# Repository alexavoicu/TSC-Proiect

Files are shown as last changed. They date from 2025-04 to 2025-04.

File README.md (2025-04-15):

Proiect OpenBook - Voicu Alexa-Andreea 331 CD

1. Diagrama bloc cu componentele



2. BOM cu componentele 3D folosite

| Qty | Component | Mouser Link | Datasheet Link |
|-----|---|---|---|
| 26  | C0402C560J4HACAUTO | [link](https://ro.mouser.com/ProductDetail/KEMET/C0402C560J4HACAUTO?qs=j%252B1pi9TdxUae00jFMoJVSQ%3D%3D) | [link](https://ro.mouser.com/datasheet/2/447/KEM_C1007_X8R_ULTRA_150C_SMD-3316375.pdf) |
| 6 | PGB1010603MR | [link](https://ro.mouser.com/ProductDetail/Littelfuse/PGB1010603MR?qs=gu7KAQ731URLg4GSnNNN7Q%3D%3D) | [link](https://www.littelfuse.com/assetdocs/pulseguard-esd-suppressors-pgb1-datasheet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) |
| 3 | MBR0530 | [link](https://ro.mouser.com/ProductDetail/onsemi/MBR0530T3G?qs=3JMERSakebpEmdUS6GetdQ%3D%3D) | [link](https://www.onsemi.com/PowerSolutions/product.do?id=MBR0530T3G) |
| 1 | USBLC6-2SC6Y | [link](https://ro.mouser.com/ProductDetail/STMicroelectronics/USBLC6-2SC6Y?qs=gNDSiZmRJS%2FOgDexvXkdow%3D%3D) | [link](https://ro.mouser.com/datasheet/2/389/usblc6_2sc6y-1852505.pdf) |
| 2 | SD0805S020S1R0 | [link](https://ro.mouser.com/ProductDetail/KYOCERA-AVX/SD0805S020S1R0?qs=jCA%252BPfw4LHbpkAoSnwrdjw%3D%3D) | [link](https://ro.mouser.com/datasheet/2/40/schottky-3165252.pdf) |
| 1 | BD5229G-TR | [link](https://ro.mouser.com/ProductDetail/ROHM-Semiconductor/BD5229G-TR?qs=4kLU8WoGk0vvnhrrYwdszw%3D%3D) | [link](https://fscdn.rohm.com/en/products/databook/datasheet/ic/power/voltage_detector/bd52xxg-e.pdf) |
| 1 | XC6220A331MR-G | [link](https://ro.mouser.com/ProductDetail/Torex-Semiconductor/XC6220A331MR-G?qs=AsjdqWjXhJ8ZSWznL1J0gg%3D%3D) | [link](https://ro.mouser.com/datasheet/2/760/xc6220-3371556.pdf) |
| 1 | FH34SRJ-24S-0.5SH_99_ | [link](https://ro.mouser.com/ProductDetail/Hirose-Connector/FH34SRJ-24S-0.5SH99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) | [link](https://ro.mouser.com/datasheet/2/185/FH34SRJ_24S_0_5SH_99__CL0580_1255_6_99_2DDrawing_0-1615044.pdf) |
| 1 | USB4110-GF-A | [link](https://ro.mouser.com/ProductDetail/GCT/USB4110-GF-A?qs=KUoIvG%2F9IlYiZvIXQjyJeA%3D%3D) | [link](https://ro.mouser.com/datasheet/2/837/GCT_USB4110_Product_Drawing___20k_cycles-3455479.pdf) |
| 1 | 112A-TAAR-R03_ATTEND | [link](https://www.digikey.ro/ro/products/detail/attend-technology/112A-TAAR-R03/17633923) | [link](https://www.attend.com.tw/data/download/file/112A-TAAR-R03_Spec.pdf) |
| 1 | TPC-4828 | [link](https://ro.mouser.com/ProductDetail/Wurth-Elektronik/744065151?qs=PGXP4M47uW53TYf%2FkIVaSQ%3D%3D) | [link](https://www.we-online.com/components/products/datasheet/744065151.pdf) |
| 1 | LG_R971-KN-1 | [link](https://ro.mouser.com/ProductDetail/ams-OSRAM/LG-R971-KN-1?qs=LsPilcdHE7EX1EB7GCLHxg%3D%3D) | [link](https://ro.mouser.com/datasheet/2/588/prd_pim_datasheet_2191277_EN_pdf-3419125.pdf) |
| 1 | MCP73831T-2ATI_OT | [link](https://ro.mouser.com/ProductDetail/Microchip-Technology/MCP73831T-2ATI-OT?qs=yUQqVecv4qsZbioEUu%252B83g%3D%3D) | [link](https://ro.mouser.com/datasheet/2/268/MCP73831_Family_Data_Sheet_DS20001984H-3441711.pdf) |
| 1 | PFMF.050.2 | [link](https://ro.mouser.com/ProductDetail/Schurter/PFMF.050.2?qs=1auRipcfynCums5v1iucSA%3D%3D) | [link](https://ro.mouser.com/datasheet/2/358/typ_PFMF-1275918.pdf) |
| 2 | Si1308EDL-T1-GE3 | [link](https://ro.mouser.com/ProductDetail/Vishay-Semiconductors/SI1308EDL-T1-GE3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) | [link](https://www.vishay.com/doc?63399) |
| 1 | DMG2305UX-7 | [link](https://ro.mouser.com/ProductDetail/Diodes-Incorporated/DMG2305UX-7?qs=L1DZKBg7t5F%2FNBHrjfxC%252Bg%3D%3D) | [link](https://www.diodes.com/assets/Datasheets/DMG2305UX.pdf) |
| 30  | RC0402FR-07100KL | [link](https://ro.mouser.com/ProductDetail/YAGEO/RC0402FR-07100KL?qs=mnq%2FyloZIXzTlUn7JAHSWg%3D%3D) | [link](https://ro.mouser.com/datasheet/2/447/YAGEO_PYu_RC_Group_51_RoHS_L_12-3313492.pdf) |
| 1 | BME688 | [link](https://ro.mouser.com/ProductDetail/Bosch-Sensortec/BME688?qs=IS%252B4QmGtzzqQoVDscqwx3A%3D%3D) | [link](https://ro.mouser.com/datasheet/2/783/bst_bme688_fl000-2307034.pdf) |
| 1 | CPH3225A | [link](https://ro.mouser.com/ProductDetail/Seiko-Semiconductors/CPH3225A?qs=3etwrb1wR%252BhUOph6lAO7eg%3D%3D) | [link](https://ro.mouser.com/datasheet/2/360/Seiko_Instruments_MicroBattery_E_20230330_2024Jan_-3561061.pdf) |
| 1 | W25Q512JVEIQ | [link](https://ro.mouser.com/ProductDetail/Winbond/W25Q512JVEIQ?qs=l7cgNqFNU1jw6svr3at6tA%3D%3D) | [link](https://ro.mouser.com/datasheet/2/949/Winbond_W25Q512JV_Datasheet-3240039.pdf) |
| 1 | ESP32-C6-WROOM-1-N8 | [link](https://ro.mouser.com/ProductDetail/Espressif-Systems/ESP32-C6-WROOM-1-N8?qs=8Wlm6%252BaMh8ST02Gmwp74cw%3D%3D) | [link](https://ro.mouser.com/datasheet/2/891/Espressif_ESP32_C6_WROOM_1__Datasheet_V0_1_PRELIMI-3239987.pdf) |
| 1 | DS3231SN# | [link](https://ro.mouser.com/ProductDetail/Analog-Devices-Maxim-Integrated/DS3231SN?qs=1eQvB6Dk1vhUlr8%2FOrV0Fw%3D%3D) | [link](https://ro.mouser.com/datasheet/2/609/DS3231-3421123.pdf) |
| 1 | MAX17048G+T10 | [link](https://ro.mouser.com/ProductDetail/Analog-Devices-Maxim-Integrated/MAX17048G%2bT10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) | [link](https://ro.mouser.com/datasheet/2/609/MAX17048_MAX17049-3469099.pdf) |
| 3 | EVQPU-JA-02K | [link](https://ro.mouser.com/ProductDetail/Panasonic/EVQ-PUJ02K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) | [link](https://4donline.ihs.com/images/VipMasterIC/IC/PANA/PANA-S-A0003211477/PANA-S-A0004028532-1.pdf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) |
| 1 | Ada 4328 | [link](https://ro.mouser.com/ProductDetail/Adafruit/4328?qs=wnTfsH77Xs6Ypm3wH0xoXg%3D%3D) | [link](https://www.snapeda.com/parts/4328/Adafruit/view-part/?ref=mouser) |
| 1 | T491B226K006AT | [link](https://ro.mouser.com/ProductDetail/KEMET/T491B226K006AT?qs=jcsBHvPDQt8yMdJgz62biA%3D%3D) | [link](https://ro.mouser.com/datasheet/2/447/KEM_T2005_T491-3316937.pdf) |

3. Descrierea în detaliu a funcționalității hardware

ESP32-C6 este microcontrollerul principal care coordonează funcționarea ebook readerului, ocupându-se de procesarea datelor și gestionarea comunicațiilor wireless. Acesta funcționează la 3.3V și dispune de interfețe versatile precum SPI, I2C și USB. Afișajul e-paper este controlat prin interfață SPI, oferind un transfer eficient al imaginilor, în timp ce aceeași magistrală SPI este partajată cu memoria externă NOR Flash, utilizată pentru stocarea firmware-ului și a resurselor grafice, și cu cardul microSD, destinat fișierelor ebook.

Prin interfața I2C sunt conectate mai multe module esențiale: ceasul de timp real DS3231SN, care păstrează ora exactă și poate semnala alarme; senzorul ambiental BME688, ce măsoară temperatura, umiditatea, presiunea și calitatea aerului; și monitorul de baterie MAX17048, care oferă informații despre tensiunea și nivelul de încărcare al bateriei. Această configurație I2C este extinsă prin conectorii Qwiic/Stemma QT, care permit adăugarea rapidă și modulară a altor senzori sau componente compatibile.

Dispozitivul este alimentat printr-un port USB-C care furnizează 5V, iar un regulator LDO convertește această tensiune la 3.3V pentru alimentarea componentelor interne. Încărcarea bateriei Li-Po este gestionată prin MCP73831, iar MAX17048 monitorizează constant nivelul bateriei. Un supercapacitor asigură alimentare de rezervă temporară, esențială pentru menținerea orei în cazul pierderii alimentării principale. Diodele TVS sunt incluse pentru protecție ESD pe liniile critice, asigurând durabilitatea dispozitivului.

E-paper-ul este optimizat energetic prin controlul alimentării cu MOSFET și prin monitorizarea semnalelor „busy” și „reset” cu ajutorul GPIO-urilor. Sistemul de stocare include atât memoria NOR Flash de 64MB, cât și cardul microSD, ambele gestionate eficient prin SPI. Interfața de utilizator este compusă din trei butoane: unul pentru resetare manuală, unul pentru intrarea în modul de boot și un buton configurabil pentru funcții speciale.

Pentru depanare și testare, placa include puncte de test (test pads) pentru semnale importante precum SPI, I2C, UART și diverse tensiuni. Acestea permit verificarea rapidă a funcționării sistemului în timpul dezvoltării sau mentenanței. Astfel, întreaga arhitectură este construită în jurul ESP32-C6, asigurând conectivitate flexibilă, eficiență energetică și extindere facilă a funcționalităților.

4. Pinii ESP32-C6

Pinii IO21 (SDA) și IO22 (SCL) sunt folosiți pentru comunicația I2C, partajați de RTC DS3231SN, senzorul BME688 și monitorul de baterie MAX17048. RTC-ul mai folosește IO0 (INT), IO1 (32KHz) și IO18 (RST). Cardul microSD folosește interfața SPI prin IO2 (MISO), IO4 (CS), IO6 (SCK) și IO7 (MOSI), iar memoria NOR Flash partajează SPI cu IO2, IO6, IO7 și adaugă IO11 pentru CS. E-paper-ul folosește IO6 și IO7 pentru date, cu IO3 (BUSY), IO5 (DC), IO10 (CS) și IO23 (RST) pentru control. Pentru butoane și funcții speciale se folosesc IO9 (BOOT), IO15 (CHANGE) și EN (RESET). Un pin rămâne neconectat (NC).

Imagini randări OpenBook

PCB 3D


Baterie


Display


OpenBook Asamblat


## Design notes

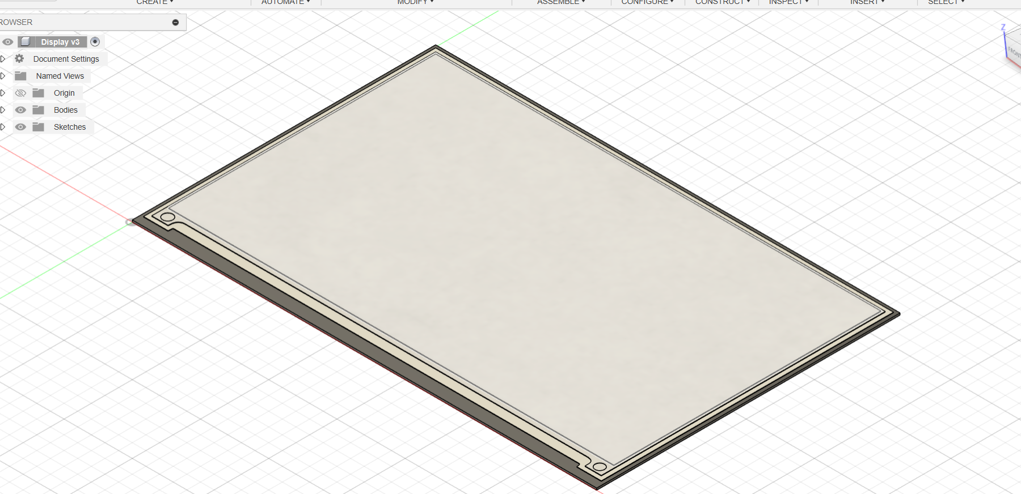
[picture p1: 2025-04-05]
Images/Display1.png

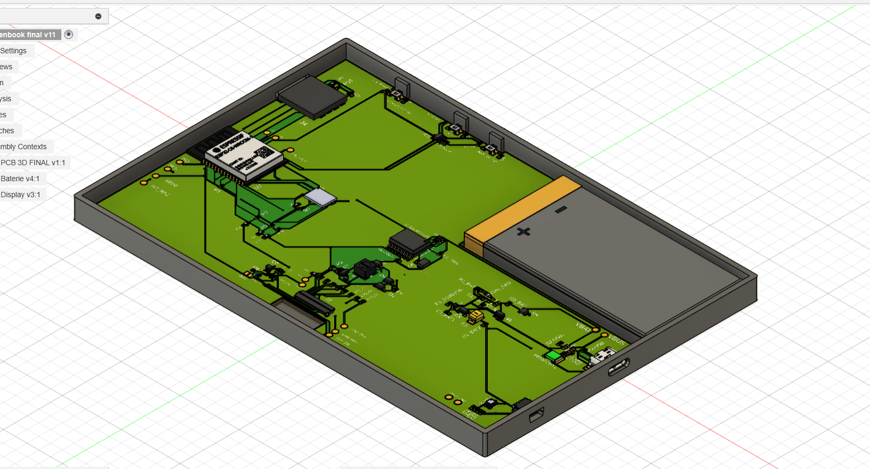
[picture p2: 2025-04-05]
Images/Openbook1.png

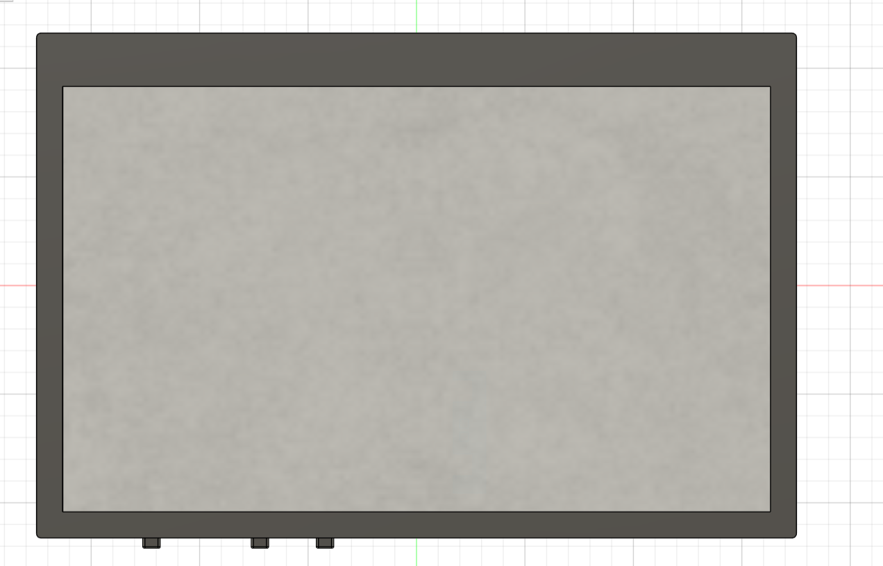
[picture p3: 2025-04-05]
Images/Openbook4.png

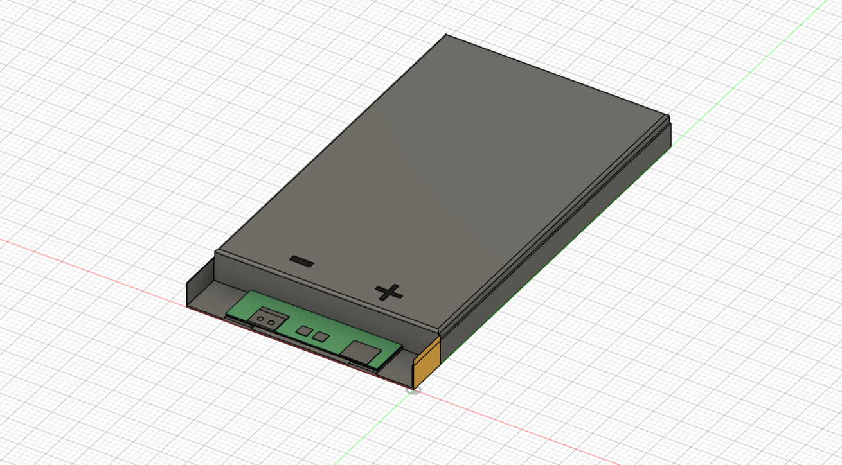
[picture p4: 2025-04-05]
Images/Baterie3.png

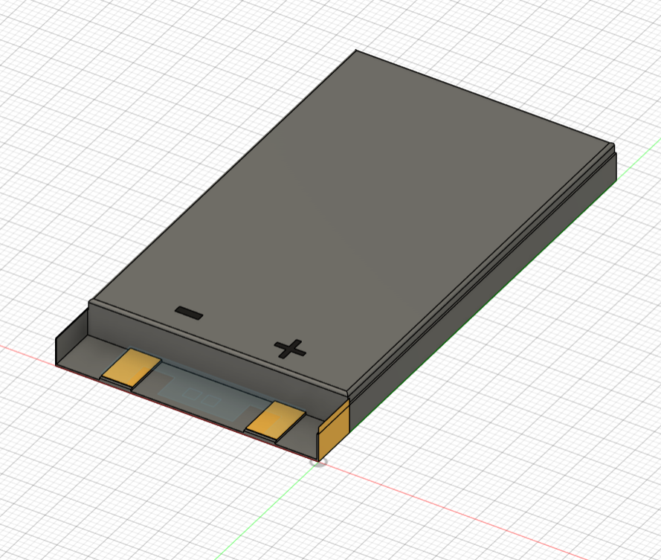
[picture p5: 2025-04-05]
Images/Baterie4.png

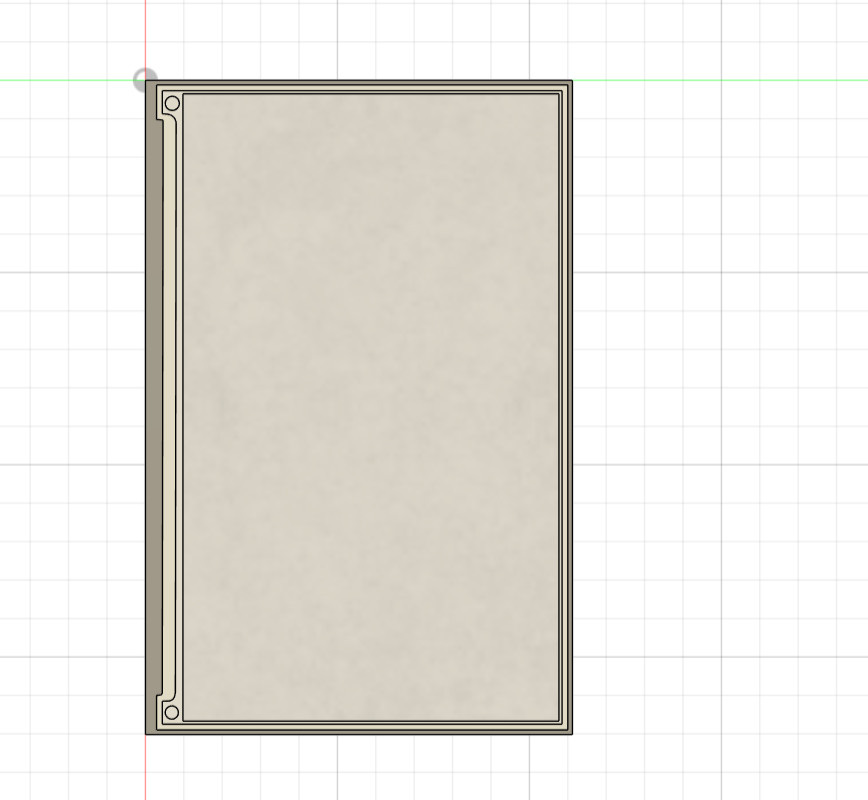
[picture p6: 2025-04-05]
Images/Display2.png

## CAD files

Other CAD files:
Mechanical/Openbook complet.f3z

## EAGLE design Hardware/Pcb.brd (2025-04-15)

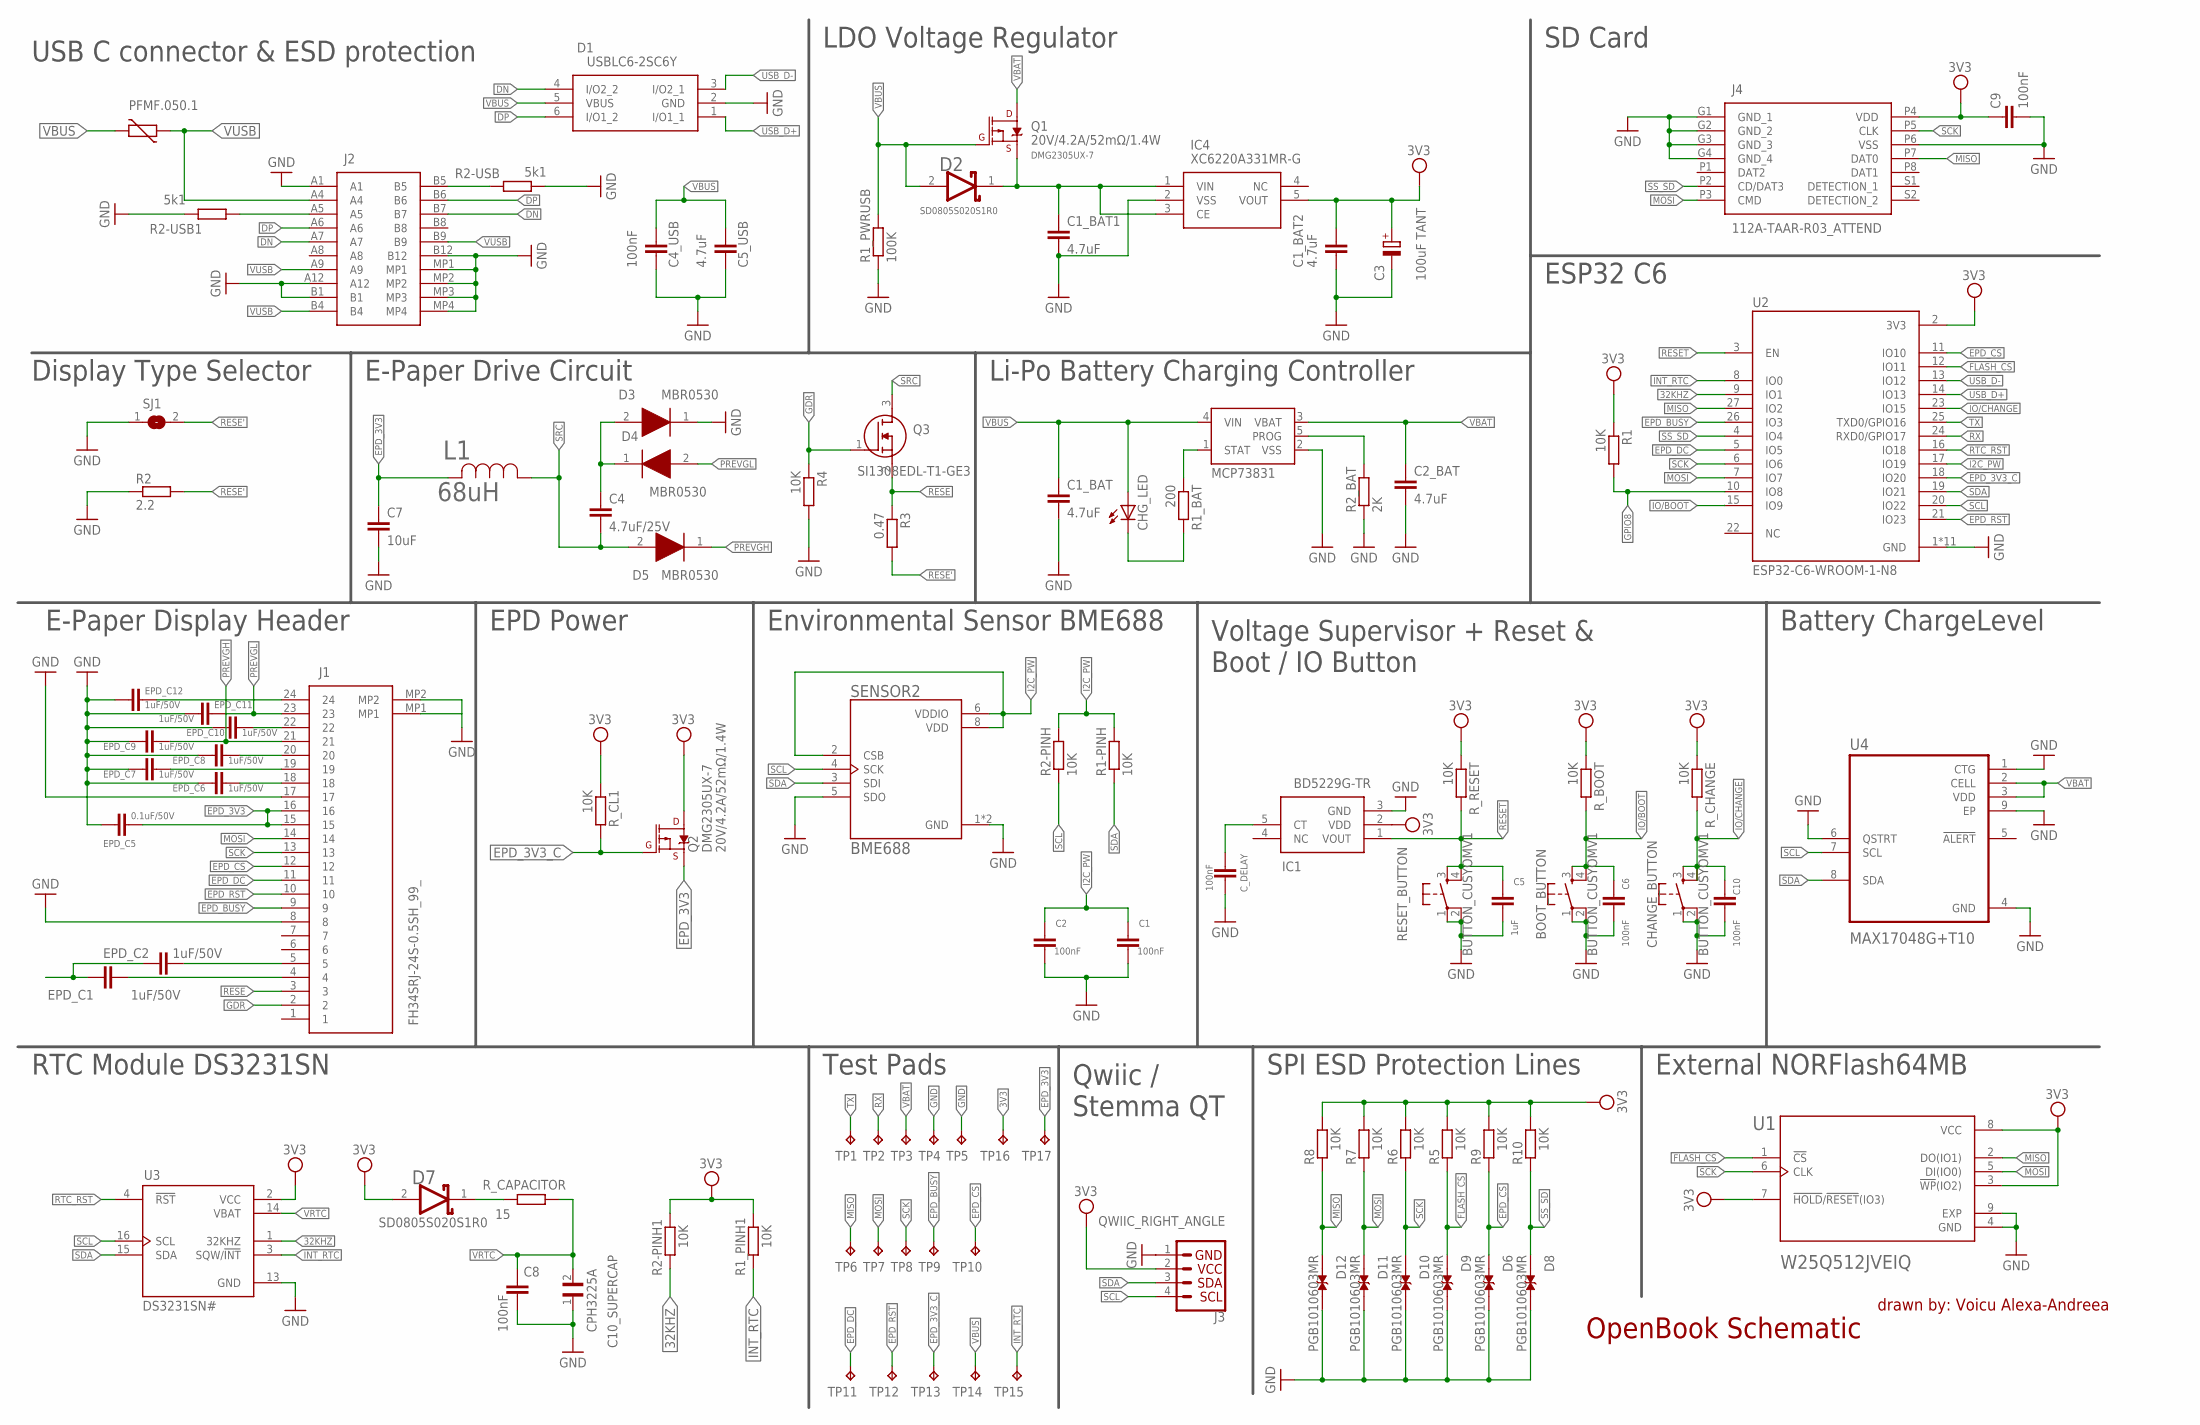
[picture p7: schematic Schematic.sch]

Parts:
BOOT_BUTTON: BUTTON_CUSYOMV1; MYBUTTON
C1, C2, C4_USB, C6, C8, C9, C10: 100nF; EAGLE-LTSPICE_C0402
C1_BAT, C1_BAT1, C1_BAT2, C2_BAT, C5_USB: 4.7uF; EAGLE-LTSPICE_C0402
C3: 100uF TANT; RCL_CT3528
C4: 4.7uF/25V; EAGLE-LTSPICE_C0402
C5: 1uF; EAGLE-LTSPICE_C0402
C7: 10uF; EAGLE-LTSPICE_C0402
C10_SUPERCAP: CPH3225A; CAPCP3225X100N
CHANGE_BUTTON: BUTTON_CUSYOMV1; MYBUTTON
CHG_LED: ADAFRUIT_LEDCHIP-LED0603; ADAFRUIT_CHIP-LED0603
C_DELAY: 100nF; EAGLE-LTSPICE_C0402
D1: USBLC6-2SC6Y; SOT95P280X145-6N
D2, D7: ESP32_WROVER_AVX---SD0805S020S1R0_AVX_SD0805S020S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; ESP32_WROVER_AVX---SD0805S020S1R0_AVX_SD0805S020S1R0_0
D3, D4, D5: MBR0530; SOD3716X135N
D6, D8, D9, D10, D11, D12: PGB1010603MR; DIOC1608X36N
EPD_C1, EPD_C2, EPD_C6, EPD_C7, EPD_C8, EPD_C9, EPD_C10, EPD_C11, EPD_C12: 1uF/50V; EAGLE-LTSPICE_C0402
EPD_C5: 0.1uF/50V; EAGLE-LTSPICE_C0402
IC1: BD5229G-TR; SOT95P280X125-5N
IC4: XC6220A331MR-G; SOT95P280X120-5N
J1: FH34SRJ-24S-0.5SH_99_; FH34SRJ24S05SH99
J2: SAMACSYS_PARTS_USB4110-GF-A; SAMACSYS_PARTS_USB4110GFA
J3: QWIIC_RIGHT_ANGLE; JST04_1MM_RA
J4: 112A-TAAR-R03_ATTEND; 112ATAARR03ATTEND
L1: 68uH; IND_4828-WE-TPC_WRE
MCP: MCP73831; ESP32_WROVER_SPARKFUN-IC-POWER_SOT23-5
PFMF.050.1: ESP32C6_VARISTORCN1812; ESP32C6_VARISTOR_CT/CN1812
Q1, Q2: 20V/4.2A/52mΩ/1.4W; ESP32_WROVER_SPARKFUN-DISCRETESEMI_SOT23-3
Q3: SI1308EDL-T1-GE3; SOT65P210X110-3N
R1, R1-PINH, R1_PINH1, R2-PINH, R2-PINH1, R4, R5, R6, R7, R8, R9, R10: 10K; ESP32_WROVER_EAGLE-LTSPICE_R0402
R1_BAT: 200; ESP32_WROVER_EAGLE-LTSPICE_R0402
R1_PWRUSB: 100K; ESP32_WROVER_EAGLE-LTSPICE_R0402
R2: 2.2; ESP32_WROVER_EAGLE-LTSPICE_R0402
R2-USB, R2-USB1: 5k1; ESP32_WROVER_EAGLE-LTSPICE_R0402
R2_BAT: 2K; ESP32_WROVER_EAGLE-LTSPICE_R0402
R3: 0.47; ESP32_WROVER_EAGLE-LTSPICE_R0402
RESET_BUTTON: BUTTON_CUSYOMV1; MYBUTTON
R_BOOT: 10K; ESP32_WROVER_EAGLE-LTSPICE_R0402
R_CAPACITOR: 15; ESP32_WROVER_EAGLE-LTSPICE_R0402
R_CHANGE: 10K; ESP32_WROVER_EAGLE-LTSPICE_R0402
R_CL1: 10K; ESP32_WROVER_EAGLE-LTSPICE_R0402
R_RESET: 10K; ESP32_WROVER_EAGLE-LTSPICE_R0402
SENSOR2: BME688; ESP32_WROVER_BME680_PSON80P300X300X100-8N
SJ1: SJ
TP1, TP2, TP3, TP4, TP5, TP6, TP7, TP8, TP9, TP10, TP11, TP12, TP13, TP14, TP15, TP16, TP17: TPTP20R; TP20R
U1: W25Q512JVEIQ; SON127P600X800X80-9N
U2: ESP32-C6-WROOM-1-N8; XCVR_ESP32-C6-WROOM-1-N8
U3: DS3231SN#; SOIC127P1032X265-16N
U4: MAX17048G+T10; SON50P200X200X80-9N

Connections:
3V3: C1_BAT2.1, C3.+, C9.1, D7.2 (ANODE), IC1.2 (VDD), IC4.5 (VOUT), J3.2, J4.P4 (VDD), Q2.3 (D), R1.1, R1_PINH1.2, R2-PINH1.2, R5.2, R6.2, R7.2, R8.2, R9.2, R10.2, R_BOOT.1, R_CHANGE.1, R_CL1.1, R_RESET.1, TP16.TP, U1.3 (!WP!(IO2)), U1.7 (!HOLD!/!RESET!(IO3)), U1.8 (VCC), U2.2 (3V3), U3.2 (VCC)
32KHZ: R2-PINH1.1, U2.9 (IO1), U3.1 (32KHZ)
DN: D1.4 (I/O2_2), J2.A7, J2.B7
DP: D1.6 (I/O1_2), J2.A6, J2.B6
EPD_3V3: C7.1, EPD_C5.1, J1.15, J1.16, L1.2, Q2.2 (S), TP17.TP
EPD_3V3_C: Q2.1 (G), R_CL1.2, TP13.TP, U2.18 (IO20)
EPD_BUSY: J1.9, TP9.TP, U2.26 (IO3)
EPD_CS: D6.1, J1.12, R9.1, TP10.TP, U2.11 (IO10)
EPD_DC: J1.11, TP11.TP, U2.5 (IO5)
EPD_RST: J1.10, TP12.TP, U2.21 (IO23)
FLASH_CS: D9.1, R5.1, U1.1 (!CS), U2.12 (IO11)
GDR: J1.2, Q3.1 (G), R4.1
GND: BOOT_BUTTON.1, BOOT_BUTTON.2, C1.2, C1_BAT.2, C1_BAT1.2, C1_BAT2.2, C2.2, C2_BAT.2, C3.-, C4_USB.2, C5.2, C5_USB.2, C6.2, C7.2, C8.2, C9.2, C10.2, C10_SUPERCAP.1, CHANGE_BUTTON.1, CHANGE_BUTTON.2, C_DELAY.2, D1.2 (GND), D3.1 (K), D6.2, D8.2, D9.2, D10.2, D11.2, D12.2, EPD_C1.2, EPD_C2.2, EPD_C5.2, EPD_C6.2, EPD_C7.2, EPD_C8.2, EPD_C9.2, EPD_C10.2, EPD_C11.2, EPD_C12.2, IC1.3 (GND), IC4.2 (VSS), J1.8, J1.17, J1.MP1, J1.MP2, J2.A1, J2.A12, J2.B1, J2.B12, J2.MP1, J2.MP2, J2.MP3, J2.MP4, J3.1, J4.G1 (GND_1), J4.G2 (GND_2), J4.G3 (GND_3), J4.G4 (GND_4), J4.P6 (VSS), MCP.2 (VSS), R1_PWRUSB.1, R2.1, R2-USB.2, R2-USB1.1, R2_BAT.1, R4.2, RESET_BUTTON.1, RESET_BUTTON.2, SENSOR2.1 (GND), SENSOR2.5 (SDO), SENSOR2.7 (GND), SJ1.1, TP4.TP, TP5.TP, U1.4 (GND), U1.9 (EXP), U2.1 (GND), U2.28 (GND), U2.29_1 (GND), U2.29_2 (GND), U2.29_3 (GND), U2.29_4 (GND), U2.29_5 (GND), U2.29_6 (GND), U2.29_7 (GND), U2.29_8 (GND), U2.29_9 (GND), U3.13 (GND), U4.1 (CTG), U4.4 (GND), U4.6 (QSTRT), U4.9 (EP)
GPIO8: R1.2, U2.10 (IO8)
I2C_PW: C1.1, C2.1, SENSOR2.2 (CSB), SENSOR2.6 (VDDIO), SENSOR2.8 (VDD), U2.17 (IO19)
INT_RTC: R1_PINH1.1, TP15.TP, U2.8 (IO0), U3.3 (SQW/!INT)
IO/BOOT: BOOT_BUTTON.3, BOOT_BUTTON.4, C6.1, R_BOOT.2, U2.15 (IO9)
IO/CHANGE: C10.1, CHANGE_BUTTON.3, CHANGE_BUTTON.4, R_CHANGE.2, U2.23 (IO15)
MISO: D12.1, J4.P7 (DAT0), R8.1, TP6.TP, U1.2 (DO(IO1)), U2.27 (IO2)
MOSI: D11.1, J1.14, J4.P3 (CMD), R7.1, TP7.TP, U1.5 (DI(IO0)), U2.7 (IO7)
unnamed: J2.A5, R2-USB1.2
unnamed: J2.B5, R2-USB.1
unnamed: C1_BAT1.1, D2.1 (CATHODE), IC4.1 (VIN), IC4.3 (CE), Q1.2 (S)
unnamed: C4.1, D3.2 (A), D4.1 (K)
unnamed: CHG_LED.C, R1_BAT.2
unnamed: MCP.1 (STAT), R1_BAT.1
unnamed: EPD_C12.1, J1.24
unnamed: R1-PINH.2, R2-PINH.2
unnamed: MCP.5 (PROG), R2_BAT.2
unnamed: EPD_C10.1, J1.22
unnamed: C_DELAY.1, IC1.5 (CT)
unnamed: EPD_C8.1, J1.20
unnamed: EPD_C7.1, J1.19
unnamed: EPD_C6.1, J1.18
unnamed: D7.1 (CATHODE), R_CAPACITOR.2
unnamed: EPD_C2.1, J1.5
unnamed: EPD_C1.1, J1.4
PREVGH: D5.1 (K), EPD_C9.1, J1.21
PREVGL: D4.2 (A), EPD_C11.1, J1.23
RESE: J1.3, Q3.2 (S), R3.1
RESE': R2.2, R3.2, SJ1.2
RESET: C5.1, IC1.1 (VOUT), RESET_BUTTON.3, RESET_BUTTON.4, R_RESET.2, U2.3 (EN)
RTC_RST: U2.16 (IO18), U3.4 (!RST)
RX: TP2.TP, U2.24 (RXD0/GPIO17)
SCK: D10.1, J1.13, J4.P5 (CLK), R6.1, TP8.TP, U1.6 (CLK), U2.6 (IO6)
SCL: J3.4, R2-PINH.1, SENSOR2.4 (SCK), U2.20 (IO22), U3.16 (SCL), U4.7 (SCL)
SDA: J3.3, R1-PINH.1, SENSOR2.3 (SDI), U2.19 (IO21), U3.15 (SDA), U4.8 (SDA)
SRC: C4.2, D5.2 (A), L1.1, Q3.3 (D)
SS_SD: D8.1, J4.P2 (CD/DAT3), R10.1, U2.4 (IO4)
TX: TP1.TP, U2.25 (TXD0/GPIO16)
USB_D+: D1.1 (I/O1_1), U2.14 (IO13)
USB_D-: D1.3 (I/O2_1), U2.13 (IO12)
VBAT: C2_BAT.1, MCP.3 (VBAT), Q1.3 (D), TP3.TP, U4.2 (CELL), U4.3 (VDD)
VBUS: C1_BAT.1, C4_USB.1, C5_USB.1, CHG_LED.A, D1.5 (VBUS), D2.2 (ANODE), MCP.4 (VIN), PFMF.050.1.2, Q1.1 (G), R1_PWRUSB.2, TP14.TP
VRTC: C8.1, C10_SUPERCAP.2, R_CAPACITOR.1, U3.14 (VBAT)
VUSB: J2.A4, J2.A9, J2.B4, J2.B9, PFMF.050.1.1

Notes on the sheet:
USB C connector & ESD protection
LDO Voltage Regulator
SD Card
ESP32 C6
Display Type Selector
E-Paper Drive Circuit
Li-Po Battery Charging Controller
E-Paper Display Header
EPD Power
Environmental Sensor BME688
Voltage Supervisor + Reset & Boot / IO Button
Battery ChargeLevel
RTC Module DS3231SN
Test Pads
Qwiic / Stemma QT
SPI ESD Protection Lines
External NORFlash64MB
OpenBook Schematic
drawn by: Voicu Alexa-Andreea

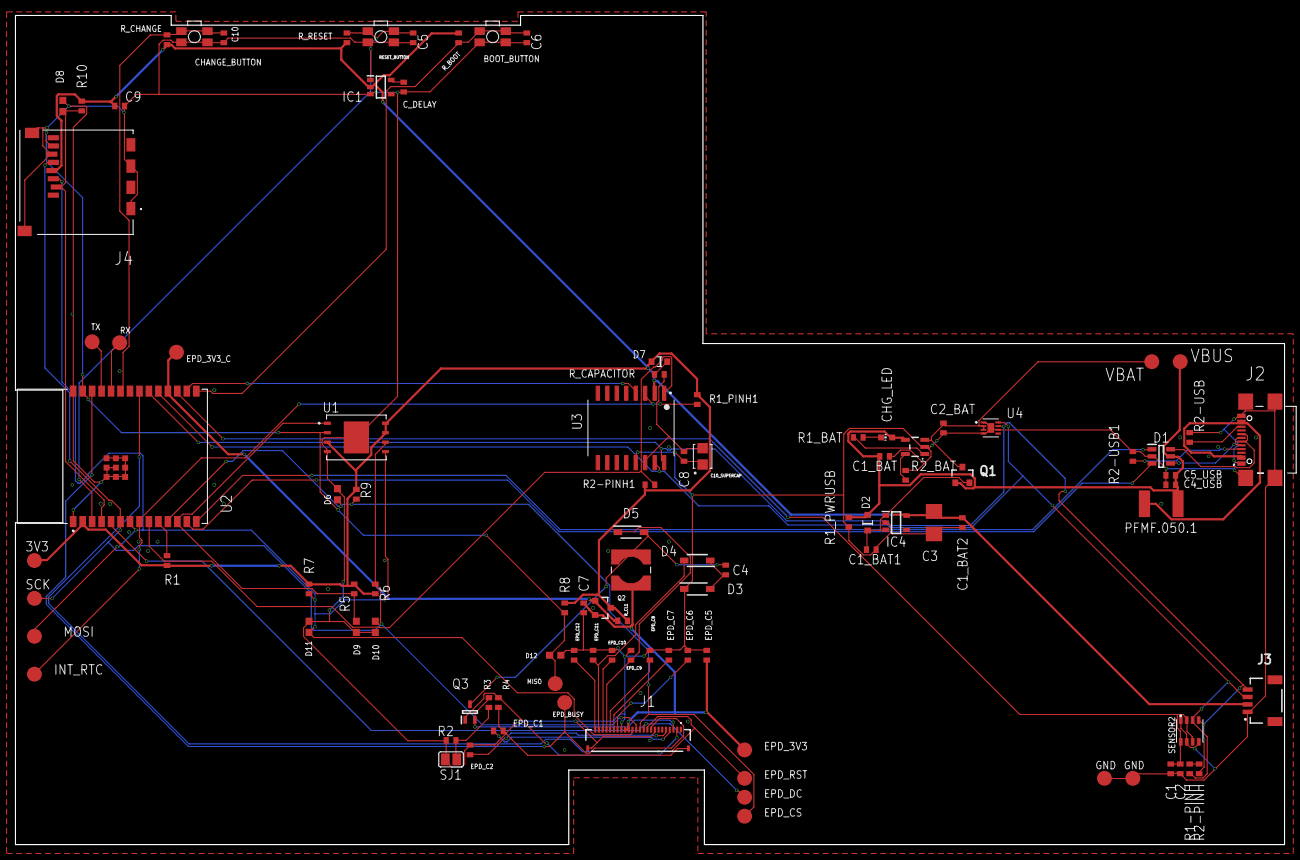
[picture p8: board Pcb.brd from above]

Board: 2 copper layers, 170.2 x 111.2 mm, 103 parts (0 on the bottom side), 56 nets.

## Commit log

2025-04-15 Added images to README – closes #4
2025-04-15 Actualizat grosimea PCB la 1mm conform cerințelor – close #2
2025-04-15 Refăcut via-stitching și planul de masă – close #1, close #3
    [Pcb.brd]

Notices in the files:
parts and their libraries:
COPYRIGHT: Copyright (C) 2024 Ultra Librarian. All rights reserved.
